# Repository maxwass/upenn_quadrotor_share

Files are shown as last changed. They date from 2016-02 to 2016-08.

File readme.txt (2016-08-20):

/*
Copyright (c) <2015>, <University of Pennsylvania:GRASP Lab>                                                             
All rights reserved.
 
Redistribution and use in source and binary forms, with or without
modification, are permitted provided that the following conditions are met:
   * Redistributions of source code must retain the above copyright
     notice, this list of conditions and the following disclaimer.
   * Redistributions in binary form must reproduce the above copyright
     notice, this list of conditions and the following disclaimer in the
      documentation and/or other materials provided with the distribution.
    * Neither the name of the university of pennsylvania nor the
      names of its contributors may be used to endorse or promote products
      derived from this software without specific prior written permission.
THIS SOFTWARE IS PROVIDED BY THE COPYRIGHT HOLDERS AND CONTRIBUTORS "AS IS" AND
ANY EXPRESS OR IMPLIED WARRANTIES, INCLUDING, BUT NOT LIMITED TO, THE IMPLIED
WARRANTIES OF MERCHANTABILITY AND FITNESS FOR A PARTICULAR PURPOSE ARE
DISCLAIMED. IN NO EVENT SHALL UNIVERSITY OF PENNSYLVANIA  BE LIABLE FOR ANY
DIRECT, INDIRECT, INCIDENTAL, SPECIAL, EXEMPLARY, OR CONSEQUENTIAL DAMAGES
(INCLUDING, BUT NOT LIMITED TO, PROCUREMENT OF SUBSTITUTE GOODS OR SERVICES;
LOSS OF USE, DATA, OR PROFITS; OR BUSINESS INTERRUPTION) HOWEVER CAUSED AND
ON ANY THEORY OF LIABILITY, WHETHER IN CONTRACT, STRICT LIABILITY, OR TORT
(INCLUDING NEGLIGENCE OR OTHERWISE) ARISING IN ANY WAY OUT OF THE USE OF THIS
SOFTWARE, EVEN IF ADVISED OF THE POSSIBILITY OF SUCH DAMAGE.

All files in this repo follow regulations above
*/ 

THe new code is now running in ROS

The main files are src/controller/src/controller.cpp - this is the controller and included most pertiant code
		   src/imu		 	     - houses imu reading and publishing code
		   src/xbee			     - houses most communication code
		   src/vision			     - houes most reading and some data prep, some claculations are done in controller.cpp for this

Basic Instructions
	- Must 'source each terminal'
	- must have a terminal open and run 'roscore'
	- each 'node' is run using 'rosrun' and then the node/file name. Ex) rosrun controller controller 
	- to recompile go to toplevel and type 'catkin_make'
////

NEW
    //Compilation Instructions
In order to run the 'main' function in a certain file, it must be uncommented, with all other 'main' functions in the other files in /src commented out. The 'main's in the other files are used for testing the functions internal to that file.

For example, to run the main controller we use g++.
ex) g++ controller.cpp vicon.cpp motor.cpp imu_inv.cpp logger.cpp utility.cpp -I /home/odroid/upenn_quad/include -lpthread -lncurses -lboost_system

This should be run when in the /src folder. Each of the files above (controller.cpp, vicon.cpp, etc) have functions used in the control loop. The -I /home/od... tells the compiler where to find the header files. We also link some libraries at the end, such as -lpthread, for the threads implementation, and -lncurses for our terminal output.

If we would like to run the test functions in somwhere, like vicon.cpp, which house the functions to recieve vicon or joystick data, we would comment out the 'main' in controller, navigate to the vicon.cpp file, uncomment its 'main, and find the compilation instructions at the top of the file.

    //Program Layout
controller.cpp: main control loop. Uses functions from imu_inv.cpp and vicon.cpp to recieve data. It performs calculations on this data to eventually ouput motor signals via a method defined in Motor.cpp. Instantiated logger object to log data.

imu.cpp: imu class which handles opening port, calibrating imu, and reading data.

psi.cpp: class to make psi continuous

logger.cpp: implementation of a simple logging class to write CSV data to a .txt file

motor.cpp: class to abstract motor commands. Handles the writing to motors via i2c.

xbee1.cpp: handles the reading of vicon/joystick data via xbee.

vicon.cpp: handles functions for vicon data. will be moved to utility.h soon

sonar.cpp: class for reading a sonar sensor

utility.h: a class of static helper functions used by a few files above.

../include/data_structs.h: custom data structures used for abstraction.

the directory send_joystick_data houses the functions necessary use the joystick for sending instructions to the quadrotor

the directory 3dPrint contains .stl files in the "import2makerbot" directory and .makerbot files in the "makerbot_ready" directory.
1).stl files can be exported to the makerbot desktop software to customize the positioning and characteristics of the print.
2) .makerbot files are the product of the process just described and are ready to be exported onto the makerbot.

If one would like to change the percent infill, number of object printed, etc just follow step one and export the resulting .makerbot file to the makerbot.

   //Misc
	setting up i2c on linux
-install i2c-tools on the linux machine with "sudo apt-get install i2c-tools"
-naviagate to the folder "/etc" and open with file modules as su with "sudo vim modules"
-once opened, paste "i2c-gpio-custom bus0=10,209,210,10,10" in the body
-reboot system.
-to detect devices on the i2c bus (such as out motors), use the command: sudo i2cdetect -y 10.

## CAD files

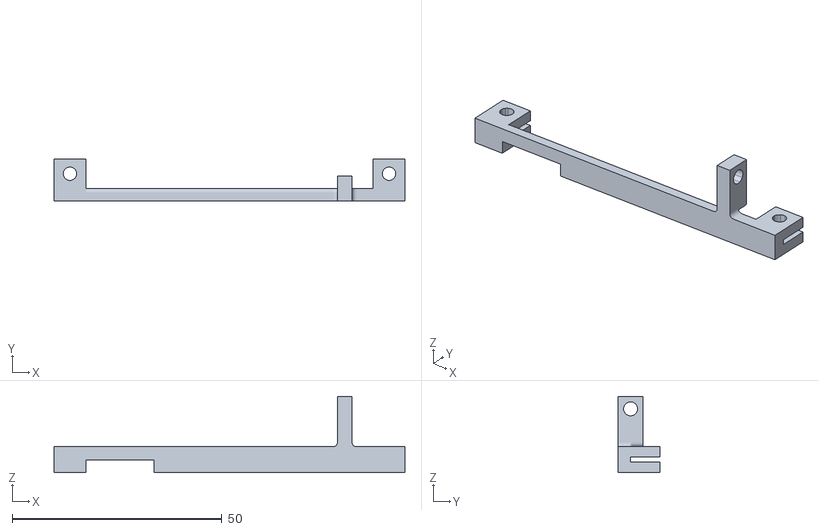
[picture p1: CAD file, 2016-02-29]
3dPrint/import2makerbot/Odroid_Holder.STL
83.6 x 10.0 x 18.2

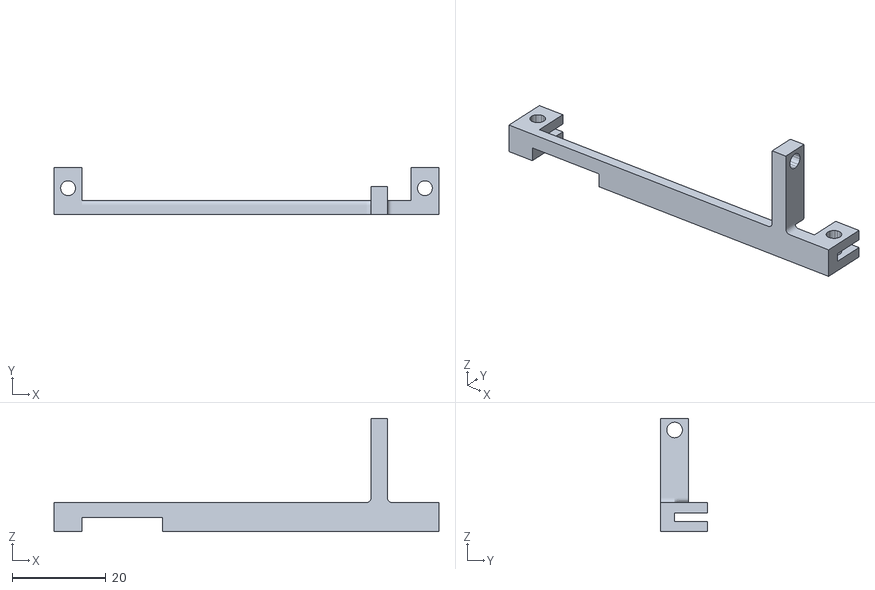
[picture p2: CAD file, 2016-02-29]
3dPrint/import2makerbot/Circuit_Holder.STL
82.1 x 10.0 x 24.2

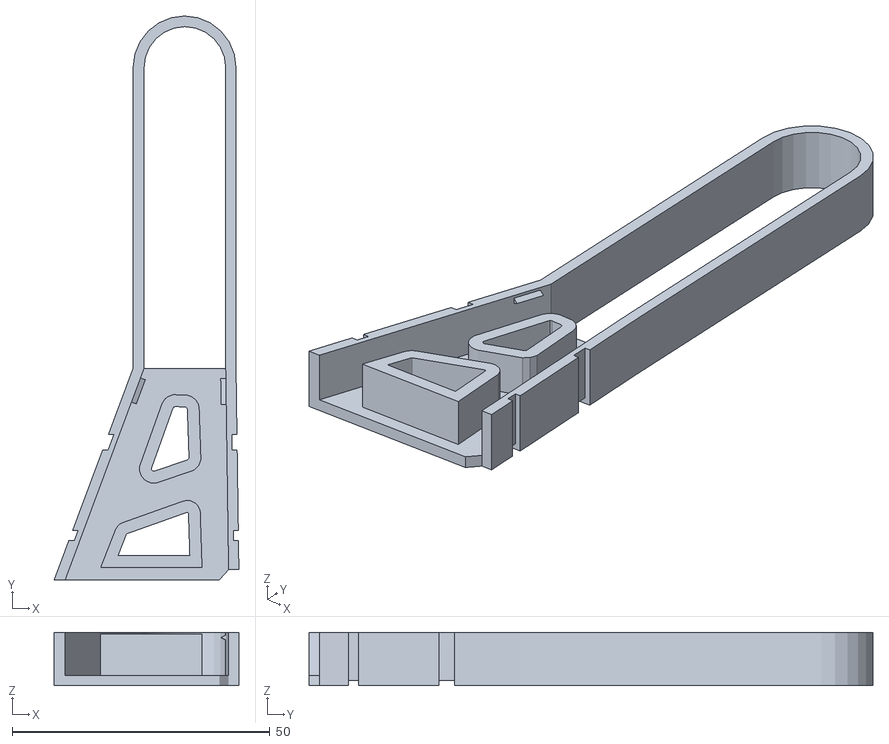
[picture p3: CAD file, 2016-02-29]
3dPrint/import2makerbot/leg.stl
35.8 x 109.3 x 10.3

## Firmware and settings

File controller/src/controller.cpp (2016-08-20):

#include "controller.h"
//g++ controller.cpp imu.cpp sonar.cpp xbee1.cpp vicon.cpp motor.cpp logger.cpp utility.cpp -I ../include -lpthread -lncurses -lboost_system -std=c++11
//initialize process-scoped data-structures
Times times;
Times time_m;
Times times_display;

Positions init_positions = {0.0};
Positions desired_positions = {0.0};

Gains gains= {0.0};
Control_command U_trim = {0};
double Ct=0.013257116418667*10;
double d=0.169;
bool MAGN = false;
bool SYSTEM_RUN = true;
bool CONTROLLER_RUN = true;
bool ESTOP = true;
bool XConfig = true;
bool AUTO_HEIGHT = false;
bool VISION_CONTROL = false;
bool DISPLAY_RUN = true;
bool LOG_DATA = true;
bool END_CALIBRATION = false;
bool AUTO_TAKEOFF = false;
bool ALREADY_TOOK_OFF = false;

float upLim = 1.5;
float lowLim = 0;
float totalTime = 2.00;
		
float display_thrust  = 0.0;



int i2cHandle, usb_imu_ivn, usb_xbee;
uint16_t display_count=0;
bool SONAR_BUBBLE_SIDES = false;
bool SONAR_BUBBLE_DOWN =  false;
bool SONAR_BUBBLE_UP   =  false;
bool REPULSE_OR_DISTANCE = false;
float desiredDist = 1000;

int repulsion_factor = 10;
int repulsion_factor_down = 20;
int repulsion_factor_up = 20;
int minDist = 500;
int maxDist = 1500;

int minDistDown = 300;
int maxDistDown = 1000;
int minDistUp = 300;
int maxDistUp = 1000;

int port;

std::string log_filename = "file.log";
logger logger(log_filename, 0, LOG_DATA);

//create our motor objects - accesible from all threads
//on this particular quadrotor the Body Frame is defined as follows:
//+x is between motors (0x2b , 0x29), +y is between (0x29 , 0x2c), 
//and by the right hand rule, +z is down.

/*
#define hardwareI2C 1
#if hardwareI2C ==1
        std::string PATH2MOTOR = "/dev/i2c-1";
#else
        std::string PATH2MOTOR = "/dev/i2c-10";
#endif
*/

//std::string PATH2MOTOR = "/dev/i2c-1";

std::string PATH2MOTOR = "/dev/i2c-10";

motor motor_1(PATH2MOTOR,1, 0x2c); //motor motor_1(1, 0x29); //0x2f
motor motor_2(PATH2MOTOR,2, 0x29);//motor motor_2(2, 0x2c); //0x2d
motor motor_3(PATH2MOTOR,3, 0x2b);//motor motor_3(3, 0x2a); //0x30
motor motor_4(PATH2MOTOR,4, 0x2a);//motor motor_4(4, 0x2b); //0x2e

SonarTest x_pos ={0}, x_neg ={0}, y_pos ={0}, y_neg ={0}, down = {0}, up = {0}; 

Sonar sonar_x_pos("/dev/ttyUSB4", minDist, maxDist);
Sonar sonar_x_neg("/dev/ttyUSB3", minDist, maxDist);
Sonar sonar_y_pos("/dev/ttyUSB0", minDist, maxDist);
Sonar sonar_y_neg("/dev/ttyUSB1", minDist, maxDist);
Sonar sonar_down("/dev/ttyUSB6",  minDistDown, maxDistDown);
Sonar sonar_up("/dev/ttyUSB5",    minDistDown, maxDistDown);

std::string path = "/dev/ttyACM0";
//Imu imu(path, 42, .007);

//Altitude altitudeObj;
//PIDController altitudeObj(gains.kp_altitude, gains.kd_altitude, gains.ki_altitude);
PIDController altitudeObj(gains.kp_altitude, gains.kd_altitude, gains.ki_altitude, 0.00, 0.00, 5.00);

int VICON_OR_JOY = 0; // 1 = VICON, 0 = JOYSTICK, 2 = both

float timeLimitImu, timeLimitXbee, timeLimitM1, timeLimitM2, timeLimitM3, timeLimitM4 = 0.0;
int incLimXbee, incLimImu = 0;
int iterUntilImuRead = 13;
int iterUntilXbeeRead = 3;
//Angles desired_angles = {0};

//Xbee be("/dev/ttyUSB3",9);
Timer timerController;
Timer timerXbee;
Timer timerImu;
Timer timerTakeOff;


#define ncurse 1
#if ncurse ==1
	#define printf(...) printw(__VA_ARGS__)
#endif

double force_m1, force_m2, force_m3, force_m4 = 0.0;


//optical flow parameters 
bool new_vo = false;
double xd, yd, zd;
double pos_x, pos_y, pos_z, vel_x, vel_y, vel_z, vel_x_filt, vel_y_filt, vel_z_filt, pos_x_, pos_y_, pos_z_, vel_x_, vel_y_;
double pos_x_temp = 0.;
double pos_y_temp = 0.; 
double pos_z_temp = 0.;
double vel_x_filt_ = 0.;
double vel_x_filt__ = 0.;
double vel_y_filt_ = 0.;
double vel_y_filt__ = 0.;
double vel_z_filt_ = 0.;
double vel_z_filt__ = 0.;
double vel_x_vo, vel_y_vo, pos_x_vo, pos_y_vo, vision_dt = 0.00;
double x_vel_d = 0.;
double y_vel_d = 0.;

State imu_data;
int8_t new_xbee_data_global = -1;
uint8_t joystick_thrust , flight_mode = 0;
Angles desired_angles = {0};
float xbee_dt = 0;

float gyro_phi_sync[12] = {0.0};
float gyro_theta_sync[12] = {0.0};

int nominal_thrust = 0;

void *control_stabilizer(void *thread_id)
{

	printf("in control stabilizer \n");
	

	Distances sonar_distances;
	Distances repulsive_forces;
	//weights is used for filter: current, one value ago, 2 values ago
	//Weights weights = {.7,.2,.1};

	//for error calculations PID: stores the actual errors, not gains
	State_Error vicon_error = {0.0};
	State_Error trans_error = {0.0};
	Vicon desired_velocity = {0.0}; 

	State imu_error = {0};
	Control_command U = {0};
	//Angles desired_angles = {0};
	
	//uint8_t joystick_thrust , flight_mode = 0;
	int succ_read;
	int new_xbee_data, new_imu_data, new_motor_write, new_sonar_data_x_pos, new_sonar_data_x_neg, new_sonar_data_y_pos, new_sonar_data_y_neg, new_sonar_data_down, new_sonar_data_up = 0;
	times.delta.tv_nsec = delta_time; //500000;
	bool first_loop = true;
	
	ros::NodeHandle nh;
	ros::Subscriber optical_flow_subscriber = nh.subscribe("/optical_flow", 1, optical_flow_callback);
	ros::Subscriber imu_sub = nh.subscribe<controller::ImuData>("imu/imu_data",1,imuCallback);
	ros::Subscriber xbee_sub = nh.subscribe<controller::XbeeData>("xbee/xbee_cmds",1,xbeeCallback); 
	//double force_m1, force_m2, force_m3, force_m4 = 0.0;

while(SYSTEM_RUN) 
  {
	
	new_xbee_data, new_imu_data, new_motor_write, new_sonar_data_x_pos, new_sonar_data_x_neg, new_sonar_data_y_pos, new_sonar_data_y_neg, new_sonar_data_down, new_sonar_data_up = -1;
	
	
	if(!ros::ok()) (SYSTEM_RUN = false);
	
	//usleep(100);
	//calc new times and delta
	float dt = timerController.update();  


/*
	new_sonar_data_x_pos = sonar_x_pos.get_sonar_data(x_pos);
	new_sonar_data_x_neg = sonar_x_neg.get_sonar_data(x_neg);
	new_sonar_data_y_pos = sonar_y_pos.get_sonar_data(y_pos);
	new_sonar_data_y_neg = sonar_y_neg.get_sonar_data(y_neg);
	new_sonar_data_down  = sonar_down.get_sonar_data(down);
	new_sonar_data_up    = sonar_up.get_sonar_data(up);
*/

	//reads input from imu (in degrees), distributes into fields of imu_data
	//get_imu_data returns 1 if read successful,< 0 if not. Reuse old values if not successful
	//new_imu_data = -2;
	//new_xbee_data = -2;
	//new_xbee_data_global = -2;
	imu_data.succ_read = false;
	new_xbee_data_global = false;
 	new_vo = false;

	timeLimitImu += dt;
	timeLimitXbee+= dt;
	timeLimitM1  += dt;
	timeLimitM2  += dt;
	timeLimitM3  += dt;
	timeLimitM4  += dt;
	
	//printf("IMU TIMER: %f  ", timeLimitImu);

	ros::spinOnce(); // get messages from published topics 
	new_imu_data = imu_data.succ_read;
	new_xbee_data = new_xbee_data_global;

	//optical flow calculations
	if(new_vo){

		vel_x = vel_x_vo/100.;
		vel_y = vel_y_vo/100.;
		
		//printf("vel_x_vo: %f, vel_y_vo: %f, vel_x: %f, vel_y: %f \n", vel_x_vo, vel_y_vo, vel_x, vel_y);

		vel_x -= gyro_theta_sync[2]/140000.;
		vel_y -= -gyro_phi_sync[2]/140000.;
		
		//printf("vel_x -= gyro_theta_sync[2]/140000: %f, gyro_theta_sync[2]: %f \n", vel_x, gyro_theta_sync[2]);
		//printf("vel_y -= gyro_phi_sync[2]/140000: %f, gyro_phi_sync[2]: %f \n", vel_y, gyro_phi_sync[2]);

		
		vel_x *= (altitudeObj.getFiltValue() + 0.05)/1.5;
	        vel_y *= (altitudeObj.getFiltValue() + 0.05)/1.5;
		
		//printf("vel_x *= (altitudeObj.getValue() + 0.05)/1.5: %f, altitudeObj.getValue(): %f \n", vel_x, altitudeObj.getValue());
		//printf("vel_y *= (altitudeObj.getValue() + 0.05)/1.5: %f, altitudeObj.getValue(): %f \n", vel_y, altitudeObj.getValue()); 


		//if(abs(vel_x) < 0.000001) printf("		VEL_X IS ZERO^^  \n\n\n\n");
		//if(abs(vel_y) < 0.000001) printf("           VEL_Y IS ZERO^^  \n\n\n\n");

		if(abs(vel_x) > 0.02 || abs(vel_y) > 0.02){
			vel_x = vel_x_;
			vel_y = vel_y_;
		}
		
		//printf("Absolute value range check: vel_x: %f, vel_y: %f \n\n", vel_x, vel_y);

		vel_x_ = vel_x;
		vel_y_ = vel_y;
		
		pos_x += vel_x;
		pos_y += vel_y;
	/*
		    result = pfilt_vo_velx.filter(vel_x, vel_x_filt);
	            if (result < 0){
	                printf("Filter Failed!!\n");
	            }
	            
	            result = pfilt_vo_vely.filter(vel_y, vel_y_filt);
	            if (result < 0){
	                printf("Filter Failed!!\n");
	            }
	*/
		trans_error.x.prop = xd - pos_x;
		trans_error.y.prop = yd - pos_y;
		trans_error.x.deriv = x_vel_d - vel_x;
		trans_error.y.deriv = y_vel_d - vel_y;
		
		trans_error.x.integral += trans_error.x.prop;
		trans_error.y.integral += trans_error.y.prop;


		//printf("BEGIN: vel_x_vo: %f \n", vel_x_vo);

		//new_vo = false;
			
		}




	//can switch between psi estimators
	if(!MAGN) imu_data.psi = imu_data.psi_gyro_integration;
	else 	  imu_data.psi = imu_data.psi_magn_continuous_calibrated;

	if (VICON_OR_JOY == 1)
	{
		printf("in vicon part");
		//new_xbee_data = xbee.get_xbee_data();

		/*if(new_xbee_data)
		{
			//calculate error from vicon
			xbee.error_vicon(vicon_error, desired_velocity, desired_positions);	
			//calculate desired attitude (phi theta phi) in desired_angles
			desired_angles_calc(desired_angles, vicon_error, gains);
		}*/
	}	
	else
	{
		Angles old_desired_angles = desired_angles;
	
		if (VISION_CONTROL == true)
		{
			desired_angles_calc(desired_angles,trans_error,gains);
		}
		if(AUTO_TAKEOFF == true)
 		{
 	
 			float t = timerTakeOff.timeSinceStart();
 			float altDesired = ((upLim - lowLim)/totalTime)*t - lowLim;
 			if(altDesired > 1.50) 
 			{
 					AUTO_HEIGHT = true;
 					VISION_CONTROL = true;
 					AUTO_TAKEOFF = false;
 					altDesired = 1.5;
 			}
 			altitudeObj.setDesiredValue(altDesired);
 		
 			if(altitudeObj.getFiltValue() > 0.500) VISION_CONTROL = true;
 
 		}	

		if(new_xbee_data < 0) ; //printf("joystick not ready to read: old data");
		//check flight mode
		    if(ESTOP)
		    {
			    if(flight_mode < 11.0) 
			    {
				CONTROLLER_RUN     = false;
				SONAR_BUBBLE_SIDES = false;
				SONAR_BUBBLE_DOWN  = false;
				SONAR_BUBBLE_UP    = false;   
				sonar_x_pos.distanceControlOff();
	
				VISION_CONTROL = false;
				AUTO_HEIGHT = false;
			
				altitudeObj.autoControlOff();
			    }
				//16 only controller
			    else if (flight_mode > 15.5 && flight_mode < 16.5) 
			    {
				SONAR_BUBBLE_SIDES = false;
                                SONAR_BUBBLE_DOWN = false;
                                SONAR_BUBBLE_UP   =  false;
				//if(sonar_x_pos.isDistControlOn()) sonar_x_pos.distanceControlOff();
				VISION_CONTROL = false;
				AUTO_HEIGHT = false;
				altitudeObj.autoControlOff();
		            }
			    //17 Bubble
			    else if(flight_mode > 16.5 && flight_mode < 17.5)
			    {
				SONAR_BUBBLE_SIDES = true;
                                //SONAR_BUBBLE_DOWN = true;
                                //SONAR_BUBBLE_UP   =  true;
				//if(!sonar_x_pos.isDistControlOn()) sonar_x_pos.distanceControlOn(desiredDist);
				VISION_CONTROL = false;
				AUTO_HEIGHT = false;
				altitudeObj.autoControlOff();
			    }
			    

			    //18 AUTO_HEIGHT
			    else if (flight_mode > 17.5 && flight_mode < 18.5)
			    {
				SONAR_BUBBLE_SIDES = false;
				SONAR_BUBBLE_DOWN =  false;
				SONAR_BUBBLE_UP   =  false;
				//if(sonar_x_pos.isDistControlOn()) sonar_x_pos.distanceControlOff();
				if(!altitudeObj.isAutoControlOn()) altitudeObj.autoControlOn(imu_data.altitude_calibrated);
			
				if(ALREADY_TOOK_OFF == false) 
				{
					AUTO_TAKEOFF = true;
 					timerTakeOff.reset();
					ALREADY_TOOK_OFF= true;
				}
				AUTO_HEIGHT = true;
				//VISION_CONTROL = true;
			       
			     }

			    //19 BOTH
			    else if (flight_mode > 18.5 && flight_mode < 19.5)
			    {
				SONAR_BUBBLE_SIDES = true;
				//SONAR_BUBBLE_DOWN =  true;
				//SONAR_BUBBLE_UP   =  true;
				if(!sonar_x_pos.isDistControlOn()) sonar_x_pos.distanceControlOn(desiredDist);			
				if(!altitudeObj.isAutoControlOn()) altitudeObj.autoControlOn(imu_data.altitude_calibrated);
				//AUTO_HEIGHT = true;
			    }


		    }
	}

	//calculate error from imu (in radians) between desired and measured state
	State imu_error = error_imu(imu_data, new_imu_data, desired_angles);
	//calculate thrust and desired acceleration
	U = thrust(imu_error,vicon_error, U_trim, joystick_thrust, gains);
	//calculate the forces of each motor and change force on motor objects and send via i2c 
	distribute_forces(U, Ct, d, force_m1, force_m2, force_m3, force_m4);
	

	//new_motor_write = send_forces(force_m1, force_m2, force_m3, force_m4);


	//printf("BOOOOL: %i\n", (LOG_DATA && ( (new_xbee_data>0) || (new_imu_data>0) || (new_sonar_data_1>0) || (new_sonar_data_2>0) || (new_sonar_data_3>0) || (new_sonar_data_4>0) ) ) );
	
	if (LOG_DATA && new_vo)

//( (new_xbee_data>0) || (new_imu_data>0) || (new_sonar_data_x_pos>0) || (new_sonar_data_x_neg>0) || (new_sonar_data_y_pos>0) || (new_sonar_data_y_neg>0) ) || (new_sonar_data_down>0) || (new_vo > 0) )   
	{
		//printf("Before Log Data  -  vel_x_vo: %f \n", vel_x_vo);
		////log_data(sonar_distances, dt,  vicon_error, imu_data, imu_error, desired_angles, U.thrust);       
		log_data(timerController.timeSinceStart(), sonar_distances, dt,  vicon_error, imu_data, imu_error, desired_angles, U.thrust);

		//printf("After  Log Data  -  vel_x_vo: %f \n\n", vel_x_vo);
	}
	if (DISPLAY_RUN) 
	{ 
		display_info(sonar_distances, new_xbee_data,  imu_data,  imu_error, vicon_error, U, desired_angles,joystick_thrust, flight_mode, times_display, time_m); 
	}



//	new_vo = false;


 }
    printf("EXIT CONTROL_STABILIZER\n");
    pthread_exit(NULL);

}

void desired_angles_calc(Angles& desired_angles, const State_Error& error, const Gains& gains)
{

    desired_angles.psi     = 0;
    desired_angles.phi     =  gains.kp_y*error.y.prop + gains.kd_y*error.y.deriv + gains.ki_y*error.y.integral; //5.y_pos_sensor - 5*y_neg_sensor
    desired_angles.theta   = -gains.kp_x*error.x.prop - gains.kd_x*error.x.deriv - gains.ki_x*error.x.integral; //5.x_pos_sensor - 5*x_neg_sensor

    if(desired_angles.phi > 10.00) desired_angles.phi = 10.00;
    else if(desired_angles.phi < -10.00) desired_angles.phi = -10.00;

    if(desired_angles.theta > 10.00) desired_angles.theta = 10.00;
    else if(desired_angles.theta < -10.00) desired_angles.theta = -10.00;

}

void stop_motors(void){
    printf("Stopping Motors ...\n");
    motor_1.send_motor_data(0, false);
    motor_2.send_motor_data(0, false);
    motor_3.send_motor_data(0, false);
    motor_4.send_motor_data(0, false);
}

void controller_on_off(bool &CONTROLLER_RUN){
    if(CONTROLLER_RUN == false){
        printf("Controller ON!!\n");
        CONTROLLER_RUN = true;
        }
    else{
        printf("Controller OFF!!\n");
        CONTROLLER_RUN = false;
        }
}
void display_on_off(bool& DISPLAY_RUN){
    if(DISPLAY_RUN == false){
        printf("DISPLAY ON!!\n");
        DISPLAY_RUN = true;
    }
    else if(DISPLAY_RUN == true){
        printf("DISPLAY OFF!!\n");
        DISPLAY_RUN = false;
    }
}
State error_imu(const State& imu_data, const int new_imu_data, const Angles& desired_angles){
    //calculate error in RADIANS
    //  xxx_d is xxx_desired.  imu outputs  degrees, we convert to radians with factor PI/180
    
    State error;
    error.phi    =  (desired_angles.phi   - imu_data.phi)      * PI/180;
    error.theta  =  (desired_angles.theta - imu_data.theta)    * PI/180;

    if (SONAR_BUBBLE_SIDES)
    {
	if(REPULSE_OR_DISTANCE)
	{
		 error.phi   += repulsion_factor*(UTILITY::dist2ScaleInv(sonar_y_neg.returnLastDistance(), minDist, maxDist) - UTILITY::dist2ScaleInv(sonar_y_pos.returnLastDistance(), minDist, maxDist))  * PI/180;
         	error.theta += repulsion_factor*(UTILITY::dist2ScaleInv(sonar_x_pos.returnLastDistance(), minDist, maxDist) - UTILITY::dist2ScaleInv(sonar_x_neg.returnLastDistance(), minDist, maxDist))  * PI/180;
	}
	else
	{
		 //error.phi   += sonar_y_pos.distance_control_output(sonar_y_pos.returnLastDistance()); 		       
		 //error.theta += sonar_x_pos.distance_control_output(sonar_x_pos.returnLastDistance());

	}
	
    }



    error.psi       =     (-imu_data.psi  + desired_angles.psi) * PI/180;
    error.phi_dot   =                           (-imu_data.phi_dot) * PI/180;
    error.theta_dot =                         (-imu_data.theta_dot) * PI/180;
    error.psi_dot   =                           (-imu_data.psi_dot) * PI/180;
   
    if(new_imu_data>0) 
    {
	
	//printf("Outside: new)imu_data: %i, imu_data.altitude_calibrated: %f \n",new_imu_data, imu_data.altitude_calibrated);
	altitudeObj.update(imu_data.altitude_calibrated, 0.00625);
     }



    error.altitude_calibrated     =     altitudeObj.getFiltPropError();
    error.altitude_deriv 	  =     altitudeObj.getFiltDerivError();
    error.altitude_integral 	  =     altitudeObj.getIntegralError();


    return error;
}
Control_command thrust(const State& imu_error, const State_Error& vicon_error, const Control_command& U_trim, const int joystick_thrust, const Gains& gains){
    //calculate thrust and acceleration
    Control_command U = {0};
    
    if(VICON_OR_JOY == 1) //VICON
    {
    	 int calc_thrust = (int) (-(gains.kp_z * vicon_error.z.prop)  -  (gains.kd_z * vicon_error.z.deriv) - (gains.ki_z * vicon_error.z.integral));
    	 U.thrust        =  calc_thrust + U_trim.thrust; 
    }
    else if(VICON_OR_JOY != 1 && AUTO_HEIGHT == false) //JOYSTICK
    {
	U.thrust        = 4 * joystick_thrust  + U_trim.thrust;
	nominal_thrust = U.thrust;
	/*xd = pos_x; 
	  yd = pos_y;*/
    }
    
    else if(AUTO_TAKEOFF == true && AUTO_HEIGHT == true) //AUTOTAKEOFF
    {
         U.thrust = nominal_thrust + gains.kp_altitude*altitudeObj.getFiltPropError() + gains.kd_altitude*altitudeObj.getFiltDerivError();  
    }
 
   else if(AUTO_HEIGHT == true) //AUTOHEIGHT
    {
        U.thrust = nominal_thrust + gains.kp_altitude*altitudeObj.getFiltPropError() + gains.kd_altitude*altitudeObj.getFiltDerivError();
        
    }
    if(VISION_CONTROL == false) {
      xd = pos_x;
      yd = pos_y;
    }
    if(SONAR_BUBBLE_DOWN)
    {
	U.thrust += repulsion_factor_down*UTILITY::dist2ScaleInv(sonar_down.returnLastDistance(), minDistDown, maxDistDown);
    }

    if(SONAR_BUBBLE_UP)
    {
        U.thrust -= repulsion_factor_up*UTILITY::dist2ScaleInv(sonar_up.returnLastDistance(), minDistUp, maxDistUp); 
    }

    
 	
    U.roll_acc  =  (gains.kp_phi   * imu_error.phi  )  +  (gains.kd_phi   * imu_error.phi_dot  )  + U_trim.roll_acc;
    U.pitch_acc =  (gains.kp_theta * imu_error.theta)  +  (gains.kd_theta * imu_error.theta_dot)  + U_trim.pitch_acc;
    U.yaw_acc   =  (gains.kp_psi   * imu_error.psi  )  +  (gains.kd_psi   * imu_error.psi_dot  )  + U_trim.yaw_acc;
   /*printf("U.yaw_acc %3.3f  =  (gains.kp_psi %3.3f   * imu_error.psi %3.3f  )  +  (gains.kd_psi %3.3f  * imu_error.psi_dot %3.3f  ) \n", 
                        U.yaw_acc, gains.kp_psi, imu_error.psi, gains.kd_psi, imu_error.psi_dot);
   if(ncurse)refresh(); 
   */
   if (U.thrust <= 0) U.thrust = 0;
   
    return U;
}

void distribute_forces(const Control_command& U, double Ct, double d, double &force_m1, double &force_m2, double &force_m3, double &force_m4){
      //calculate forces from thrusts and accelerations

  //printf("thrust: %i, U.trim: %i, yaw_acc: %f, pitch_acc: %f, Ct: %f, d: %f \n", U.thrust,U_trim.thrust, U.yaw_acc, U.pitch_acc, Ct, d);
  if(!XConfig)
    {//this is Plus Configuration
	
        force_m1 = (U.thrust/4 - (U.yaw_acc /(4*Ct)) + (U.pitch_acc /  (2*d)));
        force_m2 = (U.thrust/4 + (U.yaw_acc /(4*Ct)) - (U.roll_acc  /  (2*d)));
        force_m3 = (U.thrust/4 - (U.yaw_acc /(4*Ct)) - (U.pitch_acc /  (2*d)));
        force_m4 = (U.thrust/4 + (U.yaw_acc /(4*Ct)) + (U.roll_acc  /  (2*d)));
        
    }
      else
    {  
       //     U[1] = phi, U[2] = theta .... theta  = pitch, phi = roll, psi = yaw
    //round forces to be integers
        double force_1 = (U.thrust/4 + (U.pitch_acc/(2*d)));
        double force_2 = (U.thrust/4 - (U.roll_acc/(2*d)))  ;
        double force_3 = (U.thrust/4 - (U.pitch_acc/(2*d))); 
        double force_4 = (U.thrust/4 + (U.roll_acc/(2*d)))  ; 
        
        double x_param = sqrt(2)/2;
        
        force_m1 = x_param * (force_1 + force_2)-(U.yaw_acc/(4*Ct));
        force_m2 = x_param * (force_2 + force_3)+(U.yaw_acc/(4*Ct));
        force_m3 = x_param * (force_3 + force_4)-(U.yaw_acc/(4*Ct));
        force_m4 = x_param * (force_4 + force_1)+(U.yaw_acc/(4*Ct));
       
    }
	//printf("Dist: force_m1: %f, force_m2: %f, force_m3: %f, force_m4: %f \n", force_m1, force_m2, force_m3, force_m4);
}

int send_forces(double force_m1, double force_m2, double force_m3, double force_m4)
{

	int m1 = 0;
	int m2 = 0;
	int m3 = 0;
	int m4 = 0;
	
	if(timeLimitM1 > 0.004)
	{
		m1 = motor_1.send_motor_data( round(force_m1), CONTROLLER_RUN);
		if(m1 > 0) timeLimitM1 = 0.000;
	}
	if(timeLimitM2 > 0.004)
        {
		m2 = motor_2.send_motor_data( round(force_m2), CONTROLLER_RUN);
		if(m2 > 0) timeLimitM2 = 0.000;
        }
	if(timeLimitM3 > 0.004)
        {
		
		m3 = motor_3.send_motor_data( round(force_m3), CONTROLLER_RUN);
                if(m3 > 0) timeLimitM3 = 0.000;
        }
	if(timeLimitM4 > 0.004)
        {
		m4 = motor_4.send_motor_data( round(force_m4), CONTROLLER_RUN);
                if(m4 > 0) timeLimitM4 = 0.000;
        }


	//printf("Send: force_m1: %i, force_m2: %i, force_m3: %i, force_m4: %i \n", motor_1.get_force(), motor_2.get_force(), motor_3.get_force(), motor_4.get_force());


	if (m1 || m2 || m3 || m4) return 1;
	else			  return 0;
}
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
int main(int argc, char** argv)
{
	ros::init(argc, argv, "controller");
	//ros::NodeHandle nh;
	//ros::Subscriber optical_flow_subscriber = nh.subscribe("/optical_flow", 1, optical_flow_callback);
	//intialize desired angles, gains, U_trim, & open port ot xbee and imu
	init();
	usleep(onesecond*2);
	//if(ncurse)clear();

	configure_threads();
	usleep(onesecond*2);

	//if(ncurse)clear();
	if(ncurse) endwin();

	return 0;

}

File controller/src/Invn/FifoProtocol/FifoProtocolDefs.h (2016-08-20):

/*
* ________________________________________________________________________________________________________
* Copyright (c) 2014-2015 InvenSense Inc. Portions Copyright (c) 2014-2015 Movea. All rights reserved.
*
* This software, related documentation and any modifications thereto (collectively "Software") is subject
* to InvenSense and its licensors' intellectual property rights under U.S. and international copyright and
* other intellectual property rights laws.
*
* InvenSense and its licensors retain all intellectual property and proprietary rights in and to the Software
* and any use, reproduction, disclosure or distribution of the Software without an express license
* agreement from InvenSense is strictly prohibited.
*
* EXCEPT AS OTHERWISE PROVIDED IN A LICENSE AGREEMENT BETWEEN THE PARTIES, THE SOFTWARE IS
* PROVIDED "AS IS", WITHOUT WARRANTY OF ANY KIND, EXPRESS OR IMPLIED, INCLUDING BUT NOT LIMITED
* TO THE WARRANTIES OF MERCHANTABILITY, FITNESS FOR A PARTICULAR PURPOSE AND NON-INFRINGEMENT.
* EXCEPT AS OTHERWISE PROVIDED IN A LICENSE AGREEMENT BETWEEN THE PARTIES, IN NO EVENT SHALL
* INVENSENSE BE LIABLE FOR ANY DIRECT, SPECIAL, INDIRECT, INCIDENTAL, OR CONSEQUENTIAL DAMAGES, OR ANY
* DAMAGES WHATSOEVER RESULTING FROM LOSS OF USE, DATA OR PROFITS, WHETHER IN AN ACTION OF CONTRACT,
* NEGLIGENCE OR OTHER TORTIOUS ACTION, ARISING OUT OF OR IN CONNECTION WITH THE USE OR PERFORMANCE
* OF THE SOFTWARE.
* ________________________________________________________________________________________________________
*/

/** @defgroup 	FifoProtocolDefs	 FifoProtocolDefs
 	@brief 		FIFO Protocol definitions
    @ingroup 	FifoProtocolAdapter
    @{ 
*/

#ifndef _INV_FIFO_PROTOCOL_DEFS_H_
#define _INV_FIFO_PROTOCOL_DEFS_H_

#ifdef __cplusplus
extern "C" {
#endif

#include <stdint.h>

/** @brief Enumeration discribing the fifo type */
typedef enum FifoProtocolType {
	FIFOPROTOCOL_TYPE_COMMAND       = 0,    /**< fifo is the command fifo */
	FIFOPROTOCOL_TYPE_NORMAL        = 1,    /**< fifo is the data fifo for normal sensor */
	FIFOPROTOCOL_TYPE_WAKEUP        = 2,    /**< fifo is the data fifo for wake up sensor */
	FIFOPROTOCOL_TYPE_ANSWER        = 3,    /**< fifo is the answer fifo */
	FIFOPROTOCOL_TYPE_MAX                   /**< sentinel value for fifo type */
} FifoProtocolType;

/** @brief Error code enumeration */
typedef enum FifoProtocolError {
    FIFOPROTOCOL_ERROR_NO           = 0,    /**< success, no error */
    FIFOPROTOCOL_ERROR              = -1,   /**< unspecified error */
    FIFOPROTOCOL_ERROR_NIMPL        = -2,   /**< method is not implemented for provided argument */
    FIFOPROTOCOL_ERROR_FIFOEMPTY    = -3,   /**< fifo is empty */
    FIFOPROTOCOL_ERROR_FIFOFULL     = -4,   /**< fifo is full */
    FIFOPROTOCOL_ERROR_INCOMPLETE   = -5,   /**< not enough data to decode */
    FIFOPROTOCOL_ERROR_SIZE         = -6,   /**< size does not match what is expected or buffer is not big enough */
    FIFOPROTOCOL_ERROR_TYPE         = -7,   /**< unpected fifo type to perform required action */
    FIFOPROTOCOL_ERROR_PARSE        = -8,   /**< cannot parse a valid frame */
} FifoProtocolError;

/** @brief Option when popping/pushing from/to a fifo */
typedef enum FifoProtocolOpt {
	FIFOPROTOCOL_OPT_NONE               = 0,    /**< reserved value to indicate no particular option */
	FIFOPROTOCOL_OPT_DROP_IF_FULL       = 1,    /**< item should be drop if fifo is full */
	FIFOPROTOCOL_OPT_RESET_IF_FULL      = 2,    /**< fifo should be reset if fifo is full */
	FIFOPROTOCOL_OPT_OVERWRITE_IF_FULL  = 4,    /**< overwrite oldest item if possible */
} FifoProtocolOpt;

/** @brief outcomming frame status definition  */
typedef enum FifoProtocolStatus {
	FIFOPROTOCOL_STATUS_DATAUPDATED		= 0,
	FIFOPROTOCOL_STATUS_STATECHANGED	= 1,
	FIFOPROTOCOL_STATUS_FLUSH			= 2,
	FIFOPROTOCOL_STATUS_POLL		    = 3
} FifoProtocolStatus;

/** @brief accuracy flag definition */
typedef enum FifoProtocolAccuracy {
	FIFOPROTOCOL_ACCURACY_NO_CONTACT    = -1,
	FIFOPROTOCOL_ACCURACY_UNRELIABLE	= 0,
	FIFOPROTOCOL_ACCURACY_LOW			= 1,
	FIFOPROTOCOL_ACCURACY_MEDIUM		= 2,
	FIFOPROTOCOL_ACCURACY_HIGH			= 3
} FifoProtocolAccuracy;

/** @brief AP power mode definition */
typedef enum FifoProtocolApPowerMode {
	FIFOPROTOCOL_APPOWERMODE_SUSPEND      = 0,
	FIFOPROTOCOL_APPOWERMODE_ON           = 1,
	FIFOPROTOCOL_APPOWERMODE_IDLE         = 2,
} FifoProtocolApPowerMode;
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

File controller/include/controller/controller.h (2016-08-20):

//=================================
// include guard
#ifndef CONTROLLER_H
#define CONTROLLER_H

//=================================
// included dependencies
#include "motor.h"   //#include because controller contains a motor object
#include "data_structs.h" // user defined structs (state, control_command,gains, desired_angles)

#include "vicon.h" // change to xbee.h
#include "logger.h"
#include "imu.h"
#include "utility.h"
#include "sonar.h"
#include "xbee1.h"
#include "timer.h"
#include "altitude.h"
#include "pid_controller.h"

#include <pthread.h>
#include <stdlib.h>
#include <unistd.h>
#include <linux/i2c.h>
#include <linux/i2c-dev.h>
#include <sys/ioctl.h>
#include <fcntl.h>
#include <string.h>
#include <stdio.h>
#include <math.h>
#include <stdint.h>
//#include "receiver.h"
#include <time.h>
#include <sys/time.h>
#include <curses.h>
#include <ncurses.h>
#include <queue>
#include <vector>
#include <ctime>
#include <iostream>
#include <ros/ros.h>
#include "std_msgs/Float64MultiArray.h"
#include "controller/ImuData.h"
#include "controller/XbeeData.h"
#include <cv_bridge/cv_bridge.h>
#include <opencv2/opencv.hpp>

//time utility change

#define diff time_diff
#define tv2float timespec2float

#define NUM_THREADS 3
#define PI 3.14159265359

//To comply with NCURSES create macro to go back and forth between printf and required printw 
//#define printf(...) printw(__VA_ARGS__)
//=================================

//signal frequency = 1/frequency = frequency in Hz
int onesecond = 1000000;
int frequency = 200;
int signal_frequency = onesecond/frequency;
float delta_position = 0.1;
int max_thrust = 460;
int delta_thrust = 30;
float delta_time = 500000; // .5 ms
//The address of i2c: {between +X/+Y, -X/+Y, -X/-Y, +X/-Y}                                                                                                                           
//int address[4] = {0x2b, 0x2a, 0x2c, 0x29};
int address[4] = {0x2e, 0x30, 0x2d, 0x2f};// this is not correct

//function prototypes
void *command_input(void *thread_id);
void *control_stabilizer(void *thread_id);
void *motor_signals(void *thread_id);
void init(void);
void start_motors(void);
void stop_motors(void);
void controller_on_off(bool& CONTROLLER_RUN);
void display_on_off(bool& DISPLAY_RUN);
int send_forces(double force_m1, double force_m2, double force_m3, double force_m4);
void desired_angles_calc(Angles& desired_angles, const State_Error& error, const Gains& gains);
State error_imu(const State& imu_data, const int new_imu_data, const Angles& desired_angles);
Control_command thrust(const State& imu_error, const State_Error& vicon_error, const Control_command& U_trim, const int joystick_thrust, const Gains& gains);
void distribute_forces(const Control_command& U, double Ct, double d, double &force_m1, double &force_m2, double &force_m3, double &force_m4);
Vicon vicon_velocity(Vicon& current, Vicon& old);
void log_data(const float time, const Distances& sonar_distances, const float& dt, const State_Error& vicon_error, const State& imu_data, const State& imu_error, const Angles& , const int thrust);
//void log_data(const float time, const Distances& sonar_distances, const float& dt, const State_Error& vicon_error, const State& imu_data, const State& imu_error, const Angles& desired_angles, const int thrust);
void display_info(const Distances& sonar_distances, const int succ_read,  const State& imu_data,  const State& imu_error, const State_Error& vicon_error, const Control_command& U,  const Angles& desired_angles, const int joystick_thrust, const int flight_mode, const Times& times, const Times& time_m);
void configure_threads(void);
void optical_flow_callback(const std_msgs::Float64MultiArray::ConstPtr& msg);
void imuCallback(const controller::ImuData::ConstPtr& imuMsg);
void xbeeCallback(const controller::XbeeData::ConstPtr& xbeeMsg);
float LowPassFilter(float input, float input_old, float input_old_old, float a, float b, float c);

void calibration(void);
void set_timespec(timespec& x, timespec& y){
//set x to equal y
             x.tv_sec = y.tv_sec;
             x.tv_nsec = y.tv_nsec;
}

void time_calc(Times& times){
    //get current time, swap current and past, calc delta_t
    //printf("current time: %.8f  old time: %.8f  delta_t: %.8f\n", tv2float(times.current), tv2float(times.old), tv2float(times.delta));
 
    //update current time
    clock_gettime(CLOCK_REALTIME,&(times.current));
    times.delta = diff(times.old, times.current);

    //shift times back: set time_old_old to time_old
    set_timespec(times.old_old, times.old);

    //set time_old to current time
    set_timespec(times.old, times.current);

    time_t rawtime;
    struct tm * timeinfo;
    char buffer[80];
    time (&rawtime);
    timeinfo = localtime(&rawtime);
    strftime(buffer,80,"%d-%m-%Y %I:%M:%S",timeinfo);

    //times.date_time = buffer;
    strcpy(times.date_time,buffer); // myStr.c_str());
}
void set_initial_times(Times& times){                                                                                                                                                                       
        clock_gettime(CLOCK_REALTIME,&(times.current));
        clock_gettime(CLOCK_REALTIME,&(times.old));
        clock_gettime(CLOCK_REALTIME,&(times.old_old));
        clock_gettime(CLOCK_REALTIME,&(times.delta));
}
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

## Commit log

2016-01-20 Current quad code
2016-02-16 updated code: refactored controller.cpp, modified reading from imu and joystick, added utility file for time functions, added file for sending data from joystick to quad
2016-02-16 clarified motor layout
2016-02-16 updated i2c information
2016-02-29 added 3dPrint folder containing the .stl and .makerbot files used to print parts for the quadrotor
    [Circuit_Holder.STL, Odroid_Holder.STL, leg.stl]
2016-03-11 added arduino files and instructions
2016-04-11 Modified GetHighRateData.ino and EasyDevice.h
    Modifications required to compile GetHighRateData.ino in Arduino 1.6.5 IDE.
2016-04-13 updated with gyro_integration, new imu class, utilities class with static helper methods
2016-04-13 deleted old imu files. we know use imu class: imu.cpp imu.h
2016-05-07 included sonar class and integrated into control loop. new xbee class to read from xbee.
2016-06-28 files for reading from sonar sensors.
2016-07-01 auto_height, timer, select() motor in hardware i2c
